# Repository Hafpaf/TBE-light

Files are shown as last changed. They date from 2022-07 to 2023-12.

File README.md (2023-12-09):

# TBE light
These are the source files for TBE lights shown at MCH2022. Original wiki page can be found here: [wiki.mch2022.org](https://wiki.mch2022.org/TBE_light)

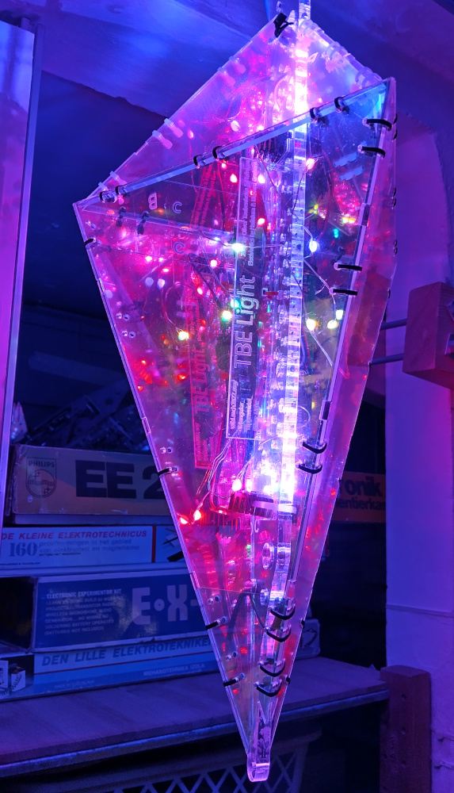
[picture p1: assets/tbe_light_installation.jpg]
TBE Light Installation


## Credits
This project was funded by the [IFCAT foundation](https://ifcat.org/) for the technology festival [MCH2022](https://mch2022.org/).

Main contributors where:
- [Hafnium](https://github.com/hafpaf/): holding everything together
- [Oliver Taubenheim](https://www.facebook.com/a2kOliverTbm): CAD modelling
- [Richard Graham](https://github.com/Richard42Graham): PCB design

A big thanks to all contributors that helped during the prototyping of this project.

## Details

The LED controller uses an ESP32 with an LAN8720A chip for Ethernet connection and is compatible with [WLED](https://github.com/Aircoookie/WLED).

The repository is split into two categories
- [PCB](./PCB/): contains Gerber files for LED controller board, as well as an component list.
-  [CAD](./CAD/): contains to Adobe Illustrator files that can be opened in [Lightburn](https://lightburnsoftware.com/) or similar laser cutting software.

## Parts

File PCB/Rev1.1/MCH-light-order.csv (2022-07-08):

Comment | Designator | Footprint | JLCPCB Part #
4.7uF | C1, C2, C3, C4, C5 | Capacitor_SMD:C_0805_2012Metric | C151869
18pF | C6, C7, C14 | Capacitor_SMD:C_0805_2012Metric | C182489
100nF | C8 | Capacitor_SMD:C_0603_1608Metric | C88136
1uF | C9 | Capacitor_SMD:C_0603_1608Metric | C90540
270pF | C10 | Capacitor_SMD:C_0603_1608Metric | C501846
100nF | C11, C12, C13 | Capacitor_SMD:C_0603_1608Metric | C88136
MountingHole_Pad | H1, H2, H3, H4, H5, H6 | MountingHole:MountingHole_3.2mm_M3_Pad | NA
FTDI | J1 | Connector_PinSocket_2.54mm:PinSocket_1x06_P2.54mm_Vertical | NA
Barrel_Jack_Switch | J2 | Connector_BarrelJack:BarrelJack_GCT_DCJ200-10-A_Horizontal | NA
USB_B_Mini | J5 | Connector_USB:USB_Micro-AB_Molex_47590-0001 | C136001
RJ45_Amphenol_RJMG1BD3B8K1ANR | J7 | Connector_RJ:RJ45_Amphenol_RJMG1BD3B8K1ANR | C163507
Screw_Terminal_01x03 | J8, J9 | Connector_PinSocket_2.54mm:PinSocket_1x03_P2.54mm_Vertical | NA
FTDI-VCC | JP1 | Jumper:SolderJumper-3_P1.3mm_Open_RoundedPad1.0x1.5mm | NA
FB/30R | L1 | Inductor_SMD:L_0805_2012Metric | C16903
12K | R1, R2 | Resistor_SMD:R_0603_1608Metric | C269454
10R | R3, R4, R6, R7 | Resistor_SMD:R_0603_1608Metric | C22859
4.7K | R5 | Capacitor_SMD:C_0805_2012Metric | C17673
4.7K | R8 | Resistor_SMD:R_0603_1608Metric | C23162
1.5K | R9 | Resistor_SMD:R_0603_1608Metric | C22843
12.1K | R10 | Resistor_SMD:R_0603_1608Metric | C22864
49R9 | R11, R12, R13, R14 | Resistor_SMD:R_0603_1608Metric | C114625
330R | R15, R16 | Resistor_SMD:R_0603_1608Metric | C23138
62R | R17 | Resistor_SMD:R_0603_1608Metric | C23222
62R | R18 | Resistor_SMD:R_0603_1608Metric | C23222
Reset | SW1 | Button_Switch_THT:SW_PUSH_6mm | C13828
Button | SW2 | Button_Switch_THT:SW_PUSH_6mm | C13828
AMS1117-3.3 | U1 | Package_TO_SOT_SMD:SOT-223-3_TabPin2 | C173386
ESP32-WROOM-32 | U2 | RF_Module:ESP32-WROOM-32 | C473012
LAN8720A | U3 | Package_DFN_QFN:QFN-24-1EP_4x4mm_P0.5mm_EP2.6x2.6mm | C45223
SN74LV4T125 | U4 | Package_SO:TSSOP-14_4.4x5mm_P0.65mm | C90755
LM2596 | U6 | LM2596-module:LM2596-Module | NA
25MHz | Y1 | Crystal:Crystal_SMD_Abracon_ABM8G-4Pin_3.2x2.5mm | C90913

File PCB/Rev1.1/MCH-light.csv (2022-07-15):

Source: | /home/richard/Documents/Kicad-projects/MCH-light/MCH-light/MCH-light.kicad_sch
Date: | Tue 28 Jun 2022 09:12:46 PM CEST
Tool: | Eeschema 6.0.5-a6ca702e91~116~ubuntu20.04.1
Generator: | /usr/share/kicad/plugins/bom_csv_grouped_by_value.py
Component Count: | 54
Collated Components:
Item | Qty | Designator | Value | LibPart | Footprint | Datasheet | JLCPCB Part #
1 | 5 | C1, C2, C3, C4, C5 | 4.7uF | Device:C | Capacitor_SMD:C_0805_2012Metric | ~ | C151869
2 | 3 | C6, C7, C14 | 18pF | Device:C | Capacitor_SMD:C_0805_2012Metric | ~ | C182489
3 | 1 | C8 | 100nF | Device:C | Capacitor_SMD:C_0603_1608Metric | ~ | C88136
4 | 1 | C9 | 1uF | Device:CP1 | Capacitor_SMD:C_0603_1608Metric |  | C90540
5 | 1 | C10 | 270pF | Device:CP1 | Capacitor_SMD:C_0603_1608Metric |  | C501846
6 | 3 | C11, C12, C13 | 100nF | Device:CP1 | Capacitor_SMD:C_0603_1608Metric |  | C88136
7 | 6 | H1, H2, H3, H4, H5, H6 | MountingHole_Pad | Mechanical:MountingHole_Pad | MountingHole:MountingHole_3.2mm_M3_Pad | ~ | NA
8 | 1 | J1 | FTDI | Connector:Conn_01x06_Male | Connector_PinSocket_2.54mm:PinSocket_1x06_P2.54mm_Vertical | ~ | NA
9 | 1 | J2 | Barrel_Jack_Switch | Connector:Barrel_Jack_Switch | Connector_BarrelJack:BarrelJack_GCT_DCJ200-10-A_Horizontal | ~ | NA
10 | 1 | J5 | USB_B_Mini | Connector:USB_B_Mini | Connector_USB:USB_Micro-AB_Molex_47590-0001 | ~ | C136001
11 | 1 | J7 | RJ45_Amphenol_RJMG1BD3B8K1ANR | Connector:RJ45_Amphenol_RJMG1BD3B8K1ANR | Connector_RJ:RJ45_Amphenol_RJMG1BD3B8K1ANR | https://www.amphenolcanada.com/ProductSearch/Drawings/AC/RJMG1BD3B8K1ANR.PDF | C163507
12 | 2 | J8, J9 | Screw_Terminal_01x03 | Connector:Screw_Terminal_01x03 | Connector_PinSocket_2.54mm:PinSocket_1x03_P2.54mm_Vertical | ~ | NA
13 | 1 | JP1 | FTDI-VCC | Jumper:SolderJumper_3_Open | Jumper:SolderJumper-3_P1.3mm_Open_RoundedPad1.0x1.5mm | ~ | NA
14 | 1 | L1 | FB/30R | Device:L | Inductor_SMD:L_0805_2012Metric | ~ | C16903
15 | 2 | R1, R2 | 12K | Device:R | Resistor_SMD:R_0603_1608Metric | ~ | C269454
16 | 4 | R3, R4, R6, R7 | 10R | Device:R | Resistor_SMD:R_0603_1608Metric | ~ | C22859
17 | 1 | R5 | 4.7K | Device:R | Capacitor_SMD:C_0805_2012Metric | ~ | C17673
18 | 1 | R8 | 4.7K | Device:R | Resistor_SMD:R_0603_1608Metric | ~ | C23162
19 | 1 | R9 | 1.5K | Device:R | Resistor_SMD:R_0603_1608Metric | ~ | C22843
20 | 1 | R10 | 12.1K | Device:R | Resistor_SMD:R_0603_1608Metric | ~ | C22864
21 | 4 | R11, R12, R13, R14 | 49R9 | Device:R | Resistor_SMD:R_0603_1608Metric | ~ | C114625
22 | 2 | R15, R16 | 330R | Device:R | Resistor_SMD:R_0603_1608Metric | ~ | C23138
23 | 1 | R17 | 62R | Device:R | Resistor_SMD:R_0603_1608Metric | ~ | C23222
24 | 1 | R18 | 62R | Device:R | Resistor_SMD:R_0603_1608Metric | ~ | C23222
25 | 1 | SW1 | Reset | phosphor:pushbutton | Button_Switch_THT:SW_PUSH_6mm |  | C13828
26 | 1 | SW2 | Button | phosphor:pushbutton | Button_Switch_THT:SW_PUSH_6mm |  | C13828
27 | 1 | U1 | AMS1117-3.3 | Regulator_Linear:AMS1117-3.3 | Package_TO_SOT_SMD:SOT-223-3_TabPin2 | http://www.advanced-monolithic.com/pdf/ds1117.pdf | C173386
28 | 1 | U2 | ESP32-WROOM-32 | RF_Module:ESP32-WROOM-32 | RF_Module:ESP32-WROOM-32 | https://www.espressif.com/sites/default/files/documentation/esp32-wroom-32_datasheet_en.pdf | C473012
29 | 1 | U3 | LAN8720A | Interface_Ethernet:LAN8720A | Package_DFN_QFN:QFN-24-1EP_4x4mm_P0.5mm_EP2.6x2.6mm | http://ww1.microchip.com/downloads/en/DeviceDoc/8720a.pdf | C45223
30 | 1 | U4 | SN74LV4T125 | 74xx:SN74LV4T125 | Package_SO:TSSOP-14_4.4x5mm_P0.65mm | https://www.ti.com/lit/ds/symlink/sn74lv4t125.pdf | C90755
31 | 1 | U6 | LM2596 | LM2596-module:LM2596 | LM2596-module:LM2596-Module |  | NA
32 | 1 | Y1 | 25MHz | Device:Crystal_GND24 | Crystal:Crystal_SMD_Abracon_ABM8G-4Pin_3.2x2.5mm | ~ | C90913

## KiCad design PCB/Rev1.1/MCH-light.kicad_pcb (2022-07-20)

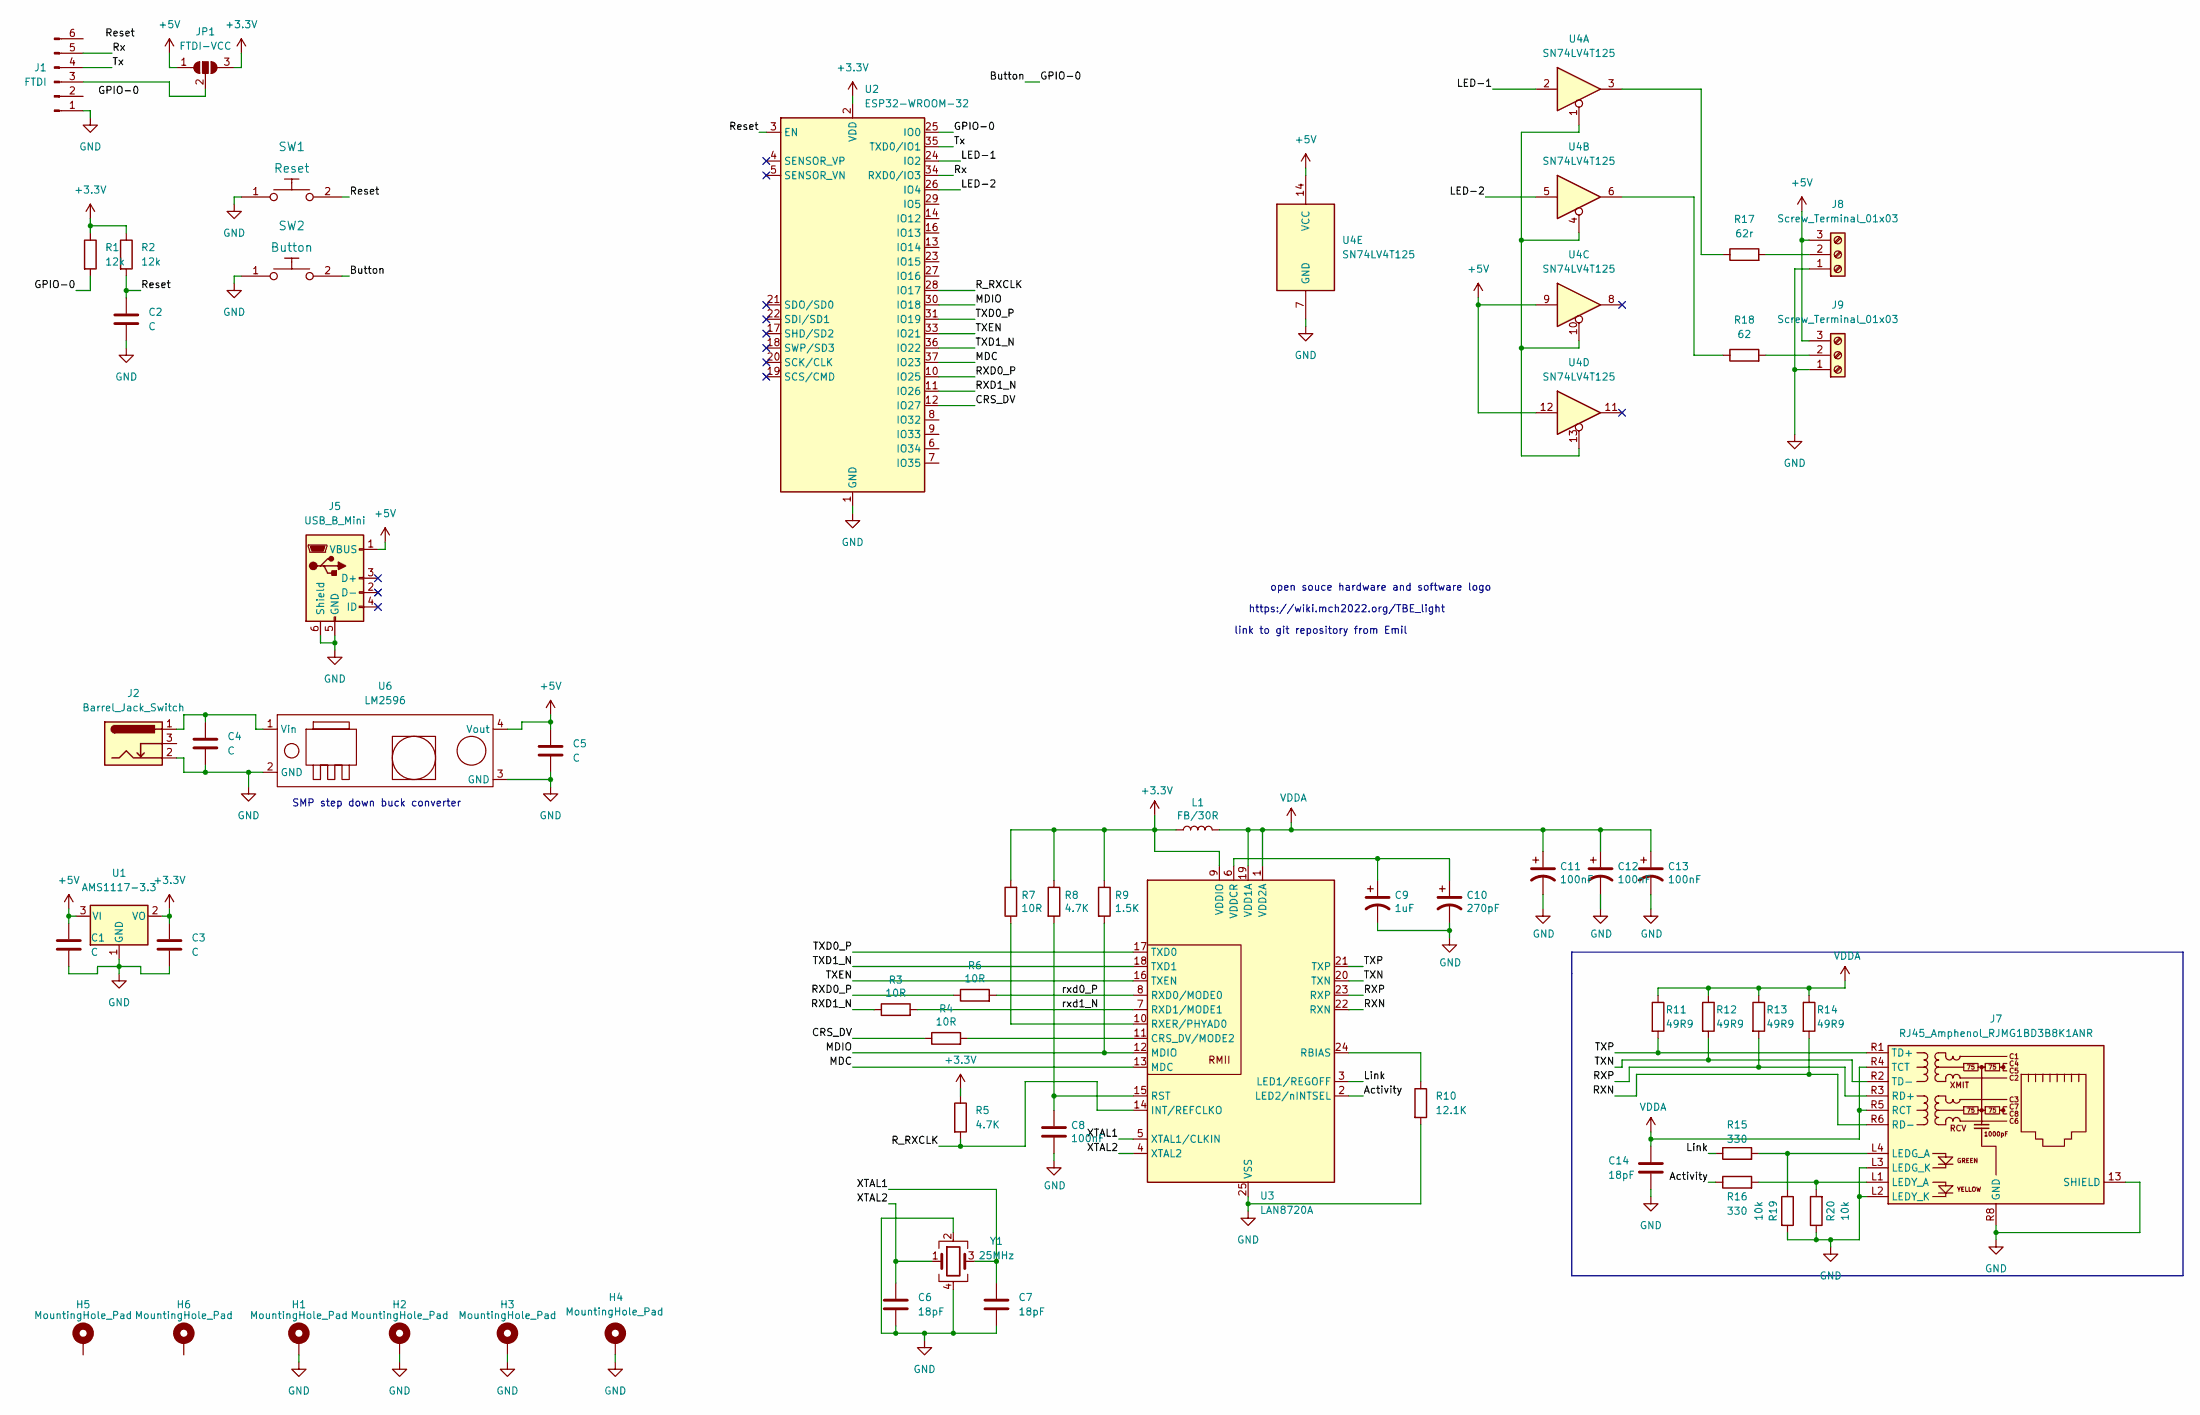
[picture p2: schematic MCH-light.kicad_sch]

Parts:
C1, C2, C3, C4, C5: C; C_0805_2012Metric
C6, C7, C14: 18pF; C_0805_2012Metric
C8, C11, C12, C13: 100nF; C_0603_1608Metric
C9: 1uF; C_0603_1608Metric
C10: 270pF; C_0603_1608Metric
H1, H2, H3, H4, H5, H6: MountingHole_Pad; MountingHole_3.2mm_M3_Pad
J1: FTDI; PinSocket_1x06_P2.54mm_Vertical
J2: Barrel_Jack_Switch; BarrelJack_GCT_DCJ200-10-A_Horizontal
J5: USB_B_Mini; USB_Micro-AB_Molex_47590-0001; JLC-pcb-part C136001
J7: RJ45_Amphenol_RJMG1BD3B8K1ANR; JLC-pcb-part C456388
J8, J9: Screw_Terminal_01x03; PinSocket_1x03_P2.54mm_Vertical
JP1: FTDI-VCC; SolderJumper-3_P1.3mm_Open_RoundedPad1.0x1.5mm
L1: FB/30R; L_0805_2012Metric
R1, R2: 12k; R_0603_1608Metric
R3, R4, R6, R7: 10R; R_0603_1608Metric
R5: 4.7K; C_0805_2012Metric
R8: 4.7K; R_0603_1608Metric
R9: 1.5K; R_0603_1608Metric
R10: 12.1K; R_0603_1608Metric
R11, R12, R13, R14: 49R9; R_0603_1608Metric
R15, R16: 330; R_0603_1608Metric
R17: 62r; R_0603_1608Metric
R18: 62; R_0603_1608Metric
R19, R20: 10k; R_0603_1608Metric
SW1: Reset; SW_PUSH_6mm; JLC-pcb-part C13828
SW2: Button; SW_PUSH_6mm; JLC-pcb-part C13828
U1: AMS1117-3.3; SOT-223-3_TabPin2; JLC-pcb-part C173386
U2: ESP32-WROOM-32; JLC-pcb-part C473012
U3: LAN8720A; QFN-24-1EP_4x4mm_P0.5mm_EP2.6x2.6mm; JLC-pcb-part C45223
U4: SN74LV4T125; TSSOP-14_4.4x5mm_P0.65mm; JLC-pcb-part C90755
U6: LM2596; LM2596-Module
Y1: 25MHz; Crystal_SMD_Abracon_ABM8G-4Pin_3.2x2.5mm

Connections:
+3V3: C3.1, JP1.3 (B), L1.1, R1.1, R2.1, R5.1, R7.2, R8.1, R9.1, U1.2 (VO), U2.2 (VDD), U3.9 (VDDIO)
+5V: C1.1, C5.1, J5.1 (VBUS), J8.3, J9.3, JP1.1 (A), U1.3 (VI), U4.9, U4.12, U4.14 (VCC), U6.4 (Vout)
/Activity: R16.1, U3.2 (LED2/nINTSEL)
/Button: R1.2, SW2.2, U2.25 (IO0)
/CRS_DV: R4.1, U2.12 (IO27)
/LED-1: U2.24 (IO2), U4.2
/LED-2: U2.26 (IO4), U4.5
/Link: R15.1, U3.3 (LED1/REGOFF)
/MDC: U2.37 (IO23), U3.13 (MDC)
/MDIO: R9.2, U2.30 (IO18), U3.12 (MDIO)
/RXD0_P: R6.1, U2.10 (IO25)
/RXD1_N: R3.1, U2.11 (IO26)
/RXN: J7.R6 (RD-), R14.2, U3.22 (RXN)
/RXP: J7.R3 (RD+), R13.2, U3.23 (RXP)
/R_RXCLK: R5.2, U2.28 (IO17), U3.14 (INT/REFCLKO)
/Reset: C2.1, R2.2, SW1.2, U2.3 (EN)
/Rx: J1.5, U2.34 (RXD0/IO3)
/TXD0_P: U2.31 (IO19), U3.17 (TXD0)
/TXD1_N: U2.36 (IO22), U3.18 (TXD1)
/TXEN: U2.33 (IO21), U3.16 (TXEN)
/TXN: J7.R2 (TD-), R12.2, U3.20 (TXN)
/TXP: J7.R1 (TD+), R11.2, U3.21 (TXP)
/Tx: J1.4, U2.35 (TXD0/IO1)
/XTAL1: C7.1, U3.5 (XTAL1/CLKIN), Y1.3
/XTAL2: C6.1, U3.4 (XTAL2), Y1.1
/rxd0_P: R6.2, U3.8 (RXD0/MODE0)
/rxd1_N: R3.2, U3.7 (RXD1/MODE1)
GND: C1.2, C2.2, C3.2, C4.2, C5.2, C6.2, C7.2, C8.2, C9.2, C10.2, C11.2, C12.2, C13.2, C14.2, H1.1, H2.1, H3.1, H4.1, J1.1, J2.2, J5.5 (GND), J5.6 (Shield), J7.13 (SHIELD), J7.L2 (LEDY_K), J7.L3 (LEDG_K), J7.R8 (GND), J8.1, J9.1, R10.2, R19.2, R20.1, SW1.1, SW2.1, U1.1 (GND), U2.1 (GND), U2.15 (GND), U2.38 (GND), U2.39 (GND), U3.25 (VSS), U4.7 (GND), U6.2 (GND), U6.3 (GND), Y1.2, Y1.4
unnamed: C4.1, J2.1, U6.1 (Vin)
unnamed: C8.1, R8.2, U3.15 (RST)
unnamed: C9.1, C10.1, U3.6 (VDDCR)
unnamed: J1.3, JP1.2 (C)
unnamed: J7.L1 (LEDY_A), R16.2, R20.2
unnamed: J7.L4 (LEDG_A), R15.2, R19.1
unnamed: J8.2, R17.2
unnamed: J9.2, R18.2
unnamed: R4.2, U3.11 (CRS_DV/MODE2)
unnamed: R7.1, U3.10 (RXER/PHYAD0)
unnamed: R10.1, U3.24 (RBIAS)
unnamed: R17.1, U4.3
unnamed: R18.1, U4.6
unnamed: U4.1, U4.4, U4.10, U4.13
VDDA: C11.1, C12.1, C13.1, C14.1, J7.R4 (TCT), J7.R5 (RCT), L1.2, R11.1, R12.1, R13.1, R14.1, U3.1 (VDD2A), U3.19 (VDD1A)

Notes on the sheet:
https://wiki.mch2022.org/TBE_light
open souce hardware and software logo
link to git repository from Emil
SMP step down buck converter

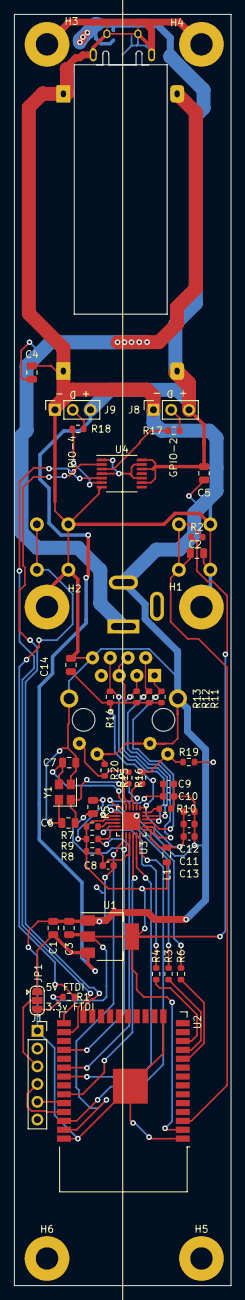
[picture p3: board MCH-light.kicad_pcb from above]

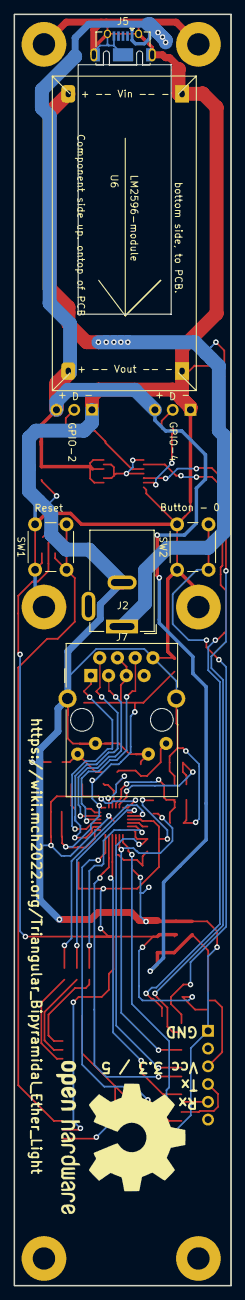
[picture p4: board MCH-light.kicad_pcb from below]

Board: 2 copper layers, 31.0 x 181.9 mm, 56 parts (6 on the bottom side), 43 nets.

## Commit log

2022-07-15 fixed some hardware bugs in the shcmatic, but have not finished the fixed layout :3
    [MCH-light-B_Adhesive.gbr, MCH-light-B_Cu.gbr, MCH-light-B_Fab.gbr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]
2022-07-20 routed updated pcb, added some more silk screen labling, :3
    [MCH-light-B_Adhesive.gbr, MCH-light-B_Cu.gbr, MCH-light-B_Fab.gbr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]
